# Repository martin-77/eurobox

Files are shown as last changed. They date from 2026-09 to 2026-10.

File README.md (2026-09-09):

# Eurobox CAD

Automated FreeCAD/OpenSCAD build and validation for the bicycle Eurobox mount.

Current target: **v50**.

## Current validated assembly preview

The single canonical repository preview is:

`cad/v50/assembly/PREVIEW_v50.png`

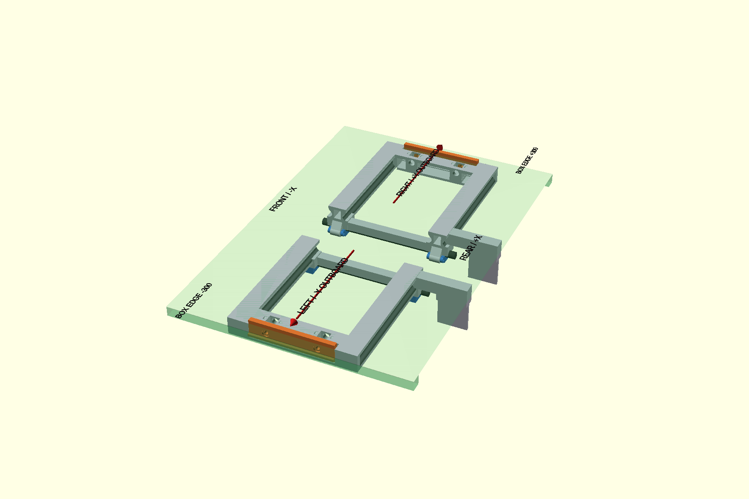
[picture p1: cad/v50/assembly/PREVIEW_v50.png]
Eurobox v50 validated assembly preview


The image is generated by the main GitHub Actions build from the same validated LEFT/RIGHT STL outputs that are published to `cad/v50/STL/`. `preview-stl/v50/` contains only the STL mirror and links back to this canonical preview; it does not keep a second PNG copy.

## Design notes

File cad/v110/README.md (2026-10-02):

# Eurobox carrier v110

V110 is a service-workaround release based on V100.

The existing V100 design is promoted unchanged, and one additional part is added:

- eurobox_v110_rack_nut_retainer_left_hand

This additional retainer is the exact X-mirror of the normal V100/V110 rack-nut retainer. Mirroring reverses the thread chirality while keeping the Z thread axis and insertion direction unchanged.

Use:
- current RIGHT base -> standard eurobox_v110_rack_nut_retainer
- current LEFT mirrored base -> eurobox_v110_rack_nut_retainer_left_hand

The left-hand service retainer tightens in the opposite rotational direction to the standard retainer.

This avoids reprinting the already-finished mirrored LEFT base. It is a compatibility workaround for the currently released mirrored female thread, not a reason to use opposite-handed threads in future base revisions.

All STL files are canonical binary STL. ASCII STL is rejected by the build/publish gate.

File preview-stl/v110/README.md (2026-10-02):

# v110 preview/print meshes

Complete binary STL mirror of cad/v110/STL/.

V110 adds a left-hand rack-nut service retainer for the currently mirrored LEFT base while retaining the standard retainer for the RIGHT base.

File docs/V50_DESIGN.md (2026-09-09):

# Eurobox v50 – finaler Konstruktionsstand

## Ziel

Werkzeuglos abnehmbarer PETG-Trägeradapter für eine quer montierte **600×400-mm-Eurobox** auf dem originalen Massload-3-leg-Gepäckträger des FOCUS THRON² EQP MY2023.

Verbindlich sind die gemessenen Datums aus `MEASUREMENTS.md`, die Parameter in `V50_DIMENSIONS.json` und die automatischen Validierungen. Alte v45/v47/v49-BREP-Geometrie ist keine Quelle für v50.

## Koordinatensystem

- X = Fahrtrichtung, **-X vorne / +X hinten**
- Y = je Seitenmodul vom Rackrohr nach außen zur Box
- Z = oben
- Rackrohrmitte je Modul = Y0/Z0

Global liegen die Rackrohrzentren bei Y=±55.335 mm und die äußeren Boxkanten exakt bei Y=±300.000 mm.

## Handed Bases und hinterer Montageanschlag

Die finale Konstruktion benötigt zwei unterschiedliche Bases:

- RIGHT: hinterer Anschlag lokal X=+150…+190 mm
- LEFT: gespiegelter Anschlag lokal X=-190…-150 mm

Das linke Modul wird bei der Montage 180° um Z gedreht. Dadurch landen beide Anschläge global am gleichen hinteren (+X) Ende. Vorne gibt es keinen Anschlag.

Der Anschlag ist 50 mm hoch, 4 mm dick und über einen tiefen Root/Gusset in den hinteren Lastpfad eingebunden. Er ist ausschließlich Montage-/Anti-Flop-Hilfe und kein zusätzlicher primärer Lastpfad. Ein separater V-Sattel an der diagonalen Rackstrebe wird nicht mehr exportiert.

## Rackbefestigung

Pro Seitenmodul zwei Klemmstationen bei X=±90 mm auf dem realen Ø12.42-mm-Rackrohr.

- obere starre Sattelhälfte in der Base
- separate flexible `rack_lower`-Hälfte
- Pivot Y=-12.0 / Z=-5.5 mm
- Pin Ø4.0 / Loch Ø4.6 mm
- Öffnungssweep 0…-75°
- Rohr muss spätestens bei -45° vollständig frei sein
- positiver Verschluss über M4-Schraube + separate Captive-Nut + Handknob
- gedruckte M4-Hardware für den Prototyp; Metall-M4 bleibt Drop-in-Option

## Tragstruktur und Druckorientierung

Die langen Lastpfade sind keine offenen I-Träger mehr. Final werden **geschlossene, verjüngte Solids** verwendet:

- 32 mm Breite oben
- 20 mm Breite unten
- 30 mm Bauhöhe
- 7 mm Taper
- Auflageoberseite Z=39.54 mm

Die komplette Base wird für den Druck 180° um X gedreht, sodass die Z=39.54-mm-Ebene auf dem Druckbett liegt. Crosshead, Guide und Cage sind auf diese Orientierung abgestimmt. Große strukturelle Supports und ein fester Unter-Rim-Bridge sind nicht vorgesehen.

## Boxklemmung – inboard statt außen

Die frühere außenliegende Schraub-/Nut-Käfiggeometrie überschritt die 600-mm-Boxbreite und ist verworfen.

Final sitzt die Boxklemmung **innen an der inneren Vertikalfläche des unteren 16.45-mm-Randes**:

- innere Randfläche lokal Y=228.215 mm
- Plattenkörper geschlossen Y=220.215…228.215 mm
- 4.2-mm-Untergriff unter der inneren Randkante
- 5.5 mm Öffnungsweg nach innen (-Y)
- 0.5 mm Klemm-Preload nach außen (+Y)
- zwei echte Durchgangsbohrungen in der Platte
- Schraubachsen X=±42 mm / Z=31 mm

Die Platte dreht nicht. Eine Spindelschulter überträgt die Klemmkraft; die axiale Retention zieht die Platte beim Öffnen aktiv zurück.

## Lead-Screw-System

Der Prototyp bleibt beim bewährten groben Druckgewinde:

- RH 8×2
- Gewindelänge 23 mm
- separate Lead-Nut-Cartridge
- Cross-Pin + C-Clip im unteren post-thread Tail
- Base selbst besitzt kein Arbeitsgewinde
- separater Knob und separate Retainer-Nut

Für die inboard-Anordnung werden Spindel, Lead-Nut, Knob und Retainer-Nut als **proper 180° Z rotation** orientiert. Es gibt keine Spiegelung der Thread-Solids; die RH-Chiralität bleibt erhalten. Positive Öffnung bewegt die Spindel nach -Y und verwendet entsprechend das umgekehrte Welt-Y-Rotationsvorzeichen.

## Harte Breitenregel

**Kein Bauteil der montierten Halterung darf die 600-mm-Eurobox seitlich überragen.**

CI ermittelt die tatsächlichen BoundBoxes von Base, Platte, Spindel, Lead-Nut, Knob, Retainer, Pin und Clip in:

- 0.5 mm Preload
- geschlossen
- 5.5 mm vollständig geöffnet

Aus Rack-CTC und dem jeweils größten lokalen Y-Maximum wird die globale Halterbreite berechnet. Obergrenze: 600.00 mm, numerische Toleranz 0.02 mm. Der Build schlägt bei Überschreitung fehl.

## Validierung vor Publish

Publish ist nur erlaubt, wenn gleichzeitig bestanden sind:

1. FreeCAD-Source-Solids gültig und einteilig;
2. STEP-Reimport gültig;
3. reales Ø12.42-mm-Rackrohr kollisionsfrei zur Base;
4. Rack-Lower-Sweep und Pivot-Hardware funktionsfähig;
5. hinterer Anschlag korrekt handed und nur hinten;
6. Box-Rim kollisionsfrei zur Base;
7. Platte geschlossen/offen kollisionsfrei und bei voller Öffnung freigegeben;
8. RH8×2 in korrekter Phase kollisionsfrei, falsche Phase mit echter Interferenz;
9. 0.5-mm-Preload mechanisch möglich;
10. vollständige Halterbreite ≤600 mm;
11. LEFT/RIGHT-STL unterschiedlich, physikalisch gespiegelt und watertight;
12. alle STL einteilig, winding-consistent und positiv volumig;
13. Assembly-Preview gerendert;
14. erst danach FCStd/STEP/STL in `cad/v50` publiziert.

## Druckziel

- Prusa CORE One L
- PETG
- 0.4-mm-Düse
- 0.20-mm-Layer
- mindestens 3 Perimeter für den strukturellen Prototyp
- kein großflächiger Support an den langen Lastpfaden oder Boxkontaktflächen

## Lastgrenze

Bis das konkrete Typenschild des montierten Massload-Trägers verifiziert ist, bleibt **16 kg Rack-Gesamtzuladung** die konservative Obergrenze. Vereinfachte 3×-Dynamikrechnungen sind ausschließlich Sanity-Checks und keine FEA oder Herstellerfreigabe.

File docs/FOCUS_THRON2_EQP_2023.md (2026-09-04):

# Focus THRON² EQP 2023 – Einbaukontext für Eurobox v50

## Zweck

Diese Datei trennt Hersteller-/Modellinformationen von direkt am Fahrrad gemessenen CAD-Daten. Werte aus Produktfotos werden **nicht** als Millimetermaße behandelt.

## Bestätigter Modellkontext

Zielrad ist ein **FOCUS THRON² EQP Modelljahr 2023**. Die FOCUS-Archivseite führt für MY23 eigene EQP-Datenblätter und eine eigene `THRON² EQP MY23`-Explosionszeichnung. Das Rad ist ein 29-Zoll-Fully mit F.O.L.D.-Hinterbau; der EQP-Gepäckträger ist ein **Massload 3-leg** und bewegt sich mit dem Hinterbau.

Für die CAD-Passung haben die Messwerte am konkreten Fahrrad Vorrang.

## Hersteller-/Quellenlage zum Gepäckträger

Die publizierte Lastangabe ist nicht völlig konsistent:

- mehrere MY23 Händler-/Spezifikationsseiten nennen den Massload 3-leg mit **25 kg max. load**;
- die aktuelle FOCUS-Archiv-FAQ für diese THRON²-EQP-Generation nennt für den eigenen Gepäckträger **16 kg**, bzw. 8 kg pro Seite.

v50 setzt deshalb **16 kg als konservative Systemobergrenze für den Originalträger**, bis Typenschild/Artikelnummer des tatsächlich montierten Gepäckträgers am Fahrrad geprüft sind. Der Adapter darf diese Herstellergrenze nicht erhöhen.

## Quellen

FOCUS Archiv THRON² EQP 2022–2024:
https://www.focus-bikes.com/int/archive/e-bikes/thron/pdp-thron-eqp-2022-2024-bosch

FOCUS Archiv / FAQ THRON² 2022–2024:
https://www.focus-bikes.com/de_de/archive/e-bikes/thron/pdp-thron-2022-2024-bosch

MY23 Händler-Spezifikation mit Massload 3-leg / 25 kg als Gegenquelle:
https://www.bikes.de/shop/e-bikes/marke.focus/focus-thron2-6-8-eqp-2023/

## Vom konkreten Fahrrad gemessene Geometrie

- oberes Gepäckträgerrohr: **Ø12.42 mm**
- Gepäckträger Außenbreite: **123.09 mm**
- Rohr Mitte–Mitte: **110.67 mm**
- nutzbare gerade Rohrlänge: ca. **220–240 mm**
- zwei Klemmpunkte pro Seitenmodul: **180 mm** Abstand
- Klemmpunkte: **X = ±90 mm**
- Rohrmitte → Euroboxkante: **244.665 mm**
- Boxauflage **Z = 39.54 mm**
- Schutzblechoberkante **Z = 34.54 mm**
- verbleibende vertikale Reserve: **5.00 mm**

## Relevanz der Focus-Geometrie

Die obere Gepäckträgerstruktur besitzt zwei lange parallele Längsrohre. Die MY23-3-leg-Konstruktion besitzt zusätzlich diagonale Streben Richtung Hinterradachse. Daraus folgen für v50 zwei getrennte Aufgaben:

1. **Hauptlast:** ausschließlich über die beiden weit auseinanderliegenden Rohrklemmen eines Seitenmoduls und die steifen Tragarme.
2. **Montage-Stabilisierung / Anti-Flop:** optionaler kleiner Anschlag an einer diagonalen Rack-Strebe, damit das Seitenmodul ohne Box nicht um das runde obere Rohr nach unten klappt.

Die Diagonalstrebe wird ausdrücklich **nicht** zum primären Lastpfad. Ihr Durchmesser und Winkel sind noch nicht gemessen; deshalb ist dort keine erfundene formschlüssige Klemme zulässig. Die erste v50-Ausführung verwendet einen universellen V-Sattel / Anschlag mit großzügiger Anpassbarkeit. Nach Vermessung kann daraus ein definierter Clip werden.

Damit bleibt die Konstruktion mit dem vollgefederten Hinterbau kompatibel: Es wird nichts zwischen Hauptrahmen und bewegtem Hinterbau verspannt.

## Herstellerlast

Bis zur Prüfung des konkreten Rack-Aufklebers gilt für die Konstruktion:

- konservative Nutzlastgrenze Originalträger: **16 kg**;
- 25 kg wird als dokumentierte MY23-Gegenangabe geführt, aber nicht als v50-Auslegungsfreigabe verwendet;
- ein 3×-Dynamikfall in der Balkenrechnung ist nur ein Geometrie-Sanity-Check und keine Freigabe oberhalb der Herstellerlast.

## Noch zu messen

- Durchmesser einer diagonalen 3-leg-Strebe;
- Winkel/Position dieser Strebe relativ zum oberen Rackrohr;
- exakte Querkontur des Schutzblechs;
- Typenschild/Artikelnummer und Lastangabe des tatsächlich montierten Massload-Trägers.

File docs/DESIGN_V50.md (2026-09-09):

# Eurobox v50 – Design-Dokumentation

Die frühere zweite, teilweise widersprüchliche v50-Konstruktionsbeschreibung wurde entfernt, damit Maße und Architektur nicht erneut auseinanderlaufen.

Verbindliche Quellen sind jetzt:

1. **`V50_DESIGN.md`** – finale Architektur und Konstruktionslogik.
2. **`V50_DIMENSIONS.json`** – maschinenlesbare harte Datums und finale Designparameter.
3. **`MEASUREMENTS.md`** – gemessene Werte und deren Herkunft.
4. **`VALIDATION_V50.md`** – Pflichtprüfungen vor einem Publish.
5. **`scripts/build_v50.py` + geordnete `apply_v50_*`-Finalisierung** – tatsächlich gebaute Geometrie.

Wichtig für den finalen v50-Stand: explizite handed LEFT/RIGHT-Bases mit genau einem hinteren Montageanschlag, geschlossene supportarme Lastpfade und eine **inboard** liegende Boxklemmung. Die komplette montierte Halterung muss innerhalb der globalen Euroboxkanten Y=±300 mm bleiben; CI behandelt 600 mm als Hard-Gate.

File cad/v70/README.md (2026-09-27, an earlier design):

# Eurobox V70 – integrated lead screw

V70 replaces the former separate knob / short retainer thread / plate clip stack
with one integrated lead screw plus one conical RH8x2 retainer nut.

## Changed parts

- `eurobox_v70_lead_screw_integrated`
  - integrated scalloped Ø30 x 7 mm grip
  - Ø13 x 2 mm outer thrust flange
  - Ø8.0 smooth journal
  - Ø8.4 x 0.8 mm pass-through hard-stop collar
  - unchanged RH8x2 working thread: core Ø6.5, major Ø8.0, pitch 2.0, length 24.0 mm

- `eurobox_v70_conical_retainer_nut`
  - same RH8x2 female geometry as the proven lead nut
  - Ø10.0 conical tip
  - Ø11.0 maximum outer diameter
  - two flats, 10.6 mm across flats
  - 5.4 mm total height

- `eurobox_v70_clamp_plate`
  - final V60 plate outline and hook retained
  - spindle bores changed to Ø8.8
  - former C-clip counterbores and service slots removed

## Fit budget

- Ø8.4 stop collar through Ø8.8 plate bore: 0.20 mm radial clearance
- Ø8.0 journal in Ø8.8 plate bore: 0.40 mm radial clearance
- retainer Ø10.0 tip over Ø8.8 bore: 0.60 mm radial capture
- retainer max Ø11.0 inside frozen BASE Ø11.8 spindle corridor: 0.40 mm radial clearance
- clamp axial play between flange and seated retainer: 0.15 mm
- inner clamp face to lead-nut front face: 7.8 mm
- retainer height: 5.4 mm
- nominal remaining gap before lead nut: 2.4 mm
- working-thread end from the outer clamp face: 32.15 mm
- former V60 working-thread end from the outer clamp face: 32.0 mm

## Frozen / reused V60 parts

The final V60 `base_left`, `base_right`, `rack_lower` and `lead_nut`
stay unchanged. The long RH8x2 working thread is deliberately kept on the
proven dimensions.

The old separate `knob`, `knob_retainer_nut` and `plate_retainer_clip`
are not used by the V70 box-clamp mechanism.

## Clamp v2 prototype

`eurobox_v70_clamp_v2` is the first full-width stepped clamp proposal based
on the measured underside geometry of the box:

- width: 187.30 mm
- total height: 88.57 mm
- screw axis: 15.00 mm above clamp bottom
- box underside: 30.00 mm above clamp bottom
- top of box protrusion: 63.57 mm above clamp bottom
- upper wall press height: 25.00 mm
- press-plane offset between protrusion and upper box wall: 18.50 mm
- V70 screw bores remain Ø8.80 mm at X=15.00 / 172.30 mm

The v2 STL is deliberately a robust fit prototype: the upper stepped block is
solid. Once the real box contact on both press planes is confirmed, the upper
section can be lightened without changing the contact geometry.

## Clamp / lead screw v3 prototype

V3 is an experimental redesign of the complete box-clamp spindle assembly. It
does not replace the frozen V60 base or lead nut.

### Clamp v3

- width: 187.30 mm
- total height: 88.57 mm
- screw axis remains 15.00 mm above clamp bottom
- box underside is 30.00 mm above clamp bottom
- nominal protrusion starts at 46.45 mm and ends at 63.57 mm
- protrusion pocket is 46.20..63.82 mm, giving 0.50 mm total vertical clearance
- lower contact is the primary clamp zone and projects to Z=27.00 mm
- upper 25 mm zone is secondary/stabilising and projects to Z=26.50 mm
- primary lower contact therefore reaches 0.50 mm farther toward the box
- the protrusion itself is recessed to the 8.00 mm backbone plane
- screw zone is reinforced to 10.00 mm thickness
- two 20 mm rear ribs connect the upper section to the screw stations
- spindle bores are Ø10.40 for rotating bushings

### Rotating bushing

One bushing is required for each spindle:

- body Ø10.00
- bore Ø8.35 for the Ø8.00 screw journal
- body length 10.25 mm
- clamp bearing thickness 10.00 mm
- resulting nominal axial freedom: 0.25 mm
- outer flange Ø14.00 x 2.00 mm

The screw shoulder and removable knob clamp the rotating bushing, not the
stationary clamp. This removes the previous conical retainer from the v3
prototype.

### Lead screw v3

From knob side toward the frozen lead nut:

- RH8x2 knob thread: 8.50 mm
- smooth Ø8.00 journal: 10.25 mm
- Ø10.80 x 2.00 mm shoulder
- RH8x2 working thread: 74.00 mm

The Ø10.80 shoulder remains inside the frozen Ø11.80 base spindle corridor
with 0.50 mm radial clearance. The working thread is the previous 24 mm plus
50 mm reserve so the spindle can remain engaged in the lead nut when the box
is removed.

### Knob v3

- separate scalloped Ø30 x 8 mm knob
- through female RH8x2 thread
- tightens against the rotating bushing flange

The screw-on knob is deliberately still a prototype. Its resistance to
self-loosening during repeated opening/closing must be checked physically
before this mechanism is treated as final.

### Binary STL build

Generate slicer-ready binary STLs explicitly; do not rely on GitHub text-file
serialization for STL output:

```sh
openscad --export-format binstl -o part.stl part.scad
```

All four locally rendered v3 meshes were checked as watertight, single-component
meshes before physical fit testing.

### GitHub binary STL validation

The v3 STLs committed in `cad/v70/STL/` are the exact locally validated
binary STL bytes. They were uploaded through the Git data API as base64 blobs
and then fetched again from the committed HEAD. Blob SHA and decoded byte
length matched the local files for all four parts:

- clamp v3: 42,684 bytes, blob `bc0a0dca49e2f693a67b32e8e2679b6cde894270`
- bushing v3: 76,884 bytes, blob `e368758d39aa2bbb31d311a99fd203082cdcaa78`
- lead screw v3: 717,384 bytes, blob `5c673d0054a5cbcd1952ab5690385c58cdc542ec`
- knob v3: 182,884 bytes, blob `49d15064ebe642e44e67df830a803bc18cfbb9c3`

This avoids the previous UTF-8 / ASCII STL serialization path.

## Clamp / spindle v4 prototype

V4 refines the v3 rotating-bushing concept.

### Recessed two-piece bushing

Each spindle uses two identical flanged bushing halves; therefore print four
halves per clamp.

- clamp screw-zone thickness: 12.00 mm
- central bushing bore: Ø10.40 mm
- flange pockets on both sides: Ø18.40 x 1.20 mm
- bushing body: Ø10.00 / bore Ø8.35
- flange: Ø18.00 x 2.20 mm
- each body length from pocket floor toward centre: 4.925 mm
- distance between clamp pocket floors: 9.60 mm
- two bodies together: 9.85 mm

The bushing stack is therefore 0.25 mm longer than the space between the pocket
floors. When the knob is tightened against the screw shoulder, the two rotating
bushing halves contact each other before either flange can clamp the stationary
clamp. The clamp keeps nominal axial freedom while the spindle assembly can be
tightened firmly.

### Clamp contact profile

The v3 box-contact strategy is retained:

- lower contact remains the primary clamp zone
- lower contact projects to Z=27.00 mm
- upper secondary contact projects to Z=26.50 mm
- primary contact therefore reaches 0.50 mm farther toward the box
- protrusion pocket remains Y=46.20..63.82 mm
- upper stabilising contact remains 25 mm high
- rear screw-zone ribs are widened to 22 mm

### Lead screw / knob

- screw-on knob thread: RH8x2, 8.50 mm
- smooth journal: Ø8.00 x 13.85 mm
- fixed screw shoulder: Ø11.20 x 2.20 mm
- frozen base spindle corridor: Ø11.80 mm
- shoulder clearance in corridor: 0.30 mm radial
- working RH8x2 thread: 74.00 mm
- knob has a Ø16.00 x 0.80 mm clamp-facing nose
- knob nose enters the Ø18.40 flange pocket and bears on the rotating bushing
  flange rather than on the stationary clamp

### STL validation

V4 STLs are committed as binary Git blobs. Before upload every local mesh was
checked as watertight and single-component. After the GitHub commit, each file
was fetched through the GitHub API and its Git blob SHA and decoded byte count
were compared against the local binary file.

Validated binary commit:

`b2da5c725c322b5b8c9f16271a7121fc01d0a1f4`

- clamp: 157884 bytes, blob `9bb2da5bfcb00de060973f195d5fac982948d2c6`
- bushing half: 76884 bytes, blob `acaf98f84e0cd1d092d5a1c521f13684dae50b1a`
- lead screw: 717384 bytes, blob `7c7a42eb9c8cdd79afef9ba98545d64c4ee73e70`
- knob: 227684 bytes, blob `e36c2ef022403b15d6af545b301b2013d89910e9`

All four GitHub blob SHAs and byte counts match their local validated binaries.

## Clamp / spindle v5 prototype

V5 refines v4 in three areas:

- the visible outer face of the screw-on knob is closed; its RH8x2 female
  thread is blind
- the upper secondary box-contact zone is reduced to 16.20 mm, exactly the
  same actual height as the lower primary-contact zone; total clamp height is
  reduced from 88.57 mm to 80.02 mm
- the bearing-centering interfaces are conical

Clamp-to-bushing:
- clamp seat Ø18.40 -> Ø10.40 over 1.60 mm
- bushing seat Ø18.00 -> Ø10.00 over 1.60 mm
- cylindrical body Ø10.00 in Ø10.40 bore
- two bushing bodies retain 0.25 mm total axial overlength, so the rotating
  bushing stack is clamped rather than the stationary clamp

Bushing-to-screw / bushing-to-knob:
- each bushing outer face has a shallow female centering cone
- screw shoulder and knob use matching male centering cones
- screw and knob do not bear directly on the clamp

Contact profile:
- lower primary contact Y=30.00..46.20 mm, height 16.20 mm
- protrusion pocket Y=46.20..63.82 mm
- upper secondary contact Y=63.82..80.02 mm, height 16.20 mm
- lower primary contact still projects 0.50 mm farther toward the box

Lead screw:
- removable-knob RH8x2 section 8.50 mm
- smooth Ø8.00 journal 13.95 mm
- conical centering shoulder, max Ø11.20 mm
- main RH8x2 working thread remains 74.00 mm

The v5 STLs are generated locally as binary STL and validated as watertight,
single-component meshes before upload. GitHub files are written as base64 Git
blobs and checked against the exact local payload.

## Clamp v6 — support-free backing

V6 changes only the clamp body. The V5 bushing halves, lead screw and knob are
unchanged and remain compatible.

V5 had the reinforced screw region extending to Z=-4 while the majority of
the rear clamp face started at Z=0. In the intended broad-face print
orientation this left a 4 mm unsupported region.

V6 extends the complete clamp backbone from Z=-4 to Z=+8, producing a single
continuous planar bed face. The added region is deliberately a closed CAD
volume rather than explicit honeycomb. Material saving and internal structure
are handled by the slicer.

Recommended baseline for this part:

- PETG
- 0.20 mm layers
- 30% gyroid
- 7 bottom layers
- 7 top layers
- 3 perimeters or the stronger project profile

At 0.20 mm, seven bottom and seven top layers provide 1.4 mm skins on both
sides of the 12 mm backbone; the remaining core is filled with gyroid. This
keeps the complete underside printable without support while retaining a
continuous load path.

The V5 box-contact dimensions and both conical bushing seats remain unchanged.

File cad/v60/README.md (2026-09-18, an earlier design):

# Eurobox carrier v60

Canonical clean rebuild generated and hard-validated by `scripts/build_v60.py`, `scripts/build_v60_continuous_carrier.py` and `scripts/build_v60_full.py`.

Structural principle: one continuous rack-side carrier. The two rack clamps and the rear stop hang from this carrier; the long box-support holms fuse into the same load path.

- `FCStd/` — individual editable FreeCAD parts
- `STEP/` — neutral CAD exports
- `STL/` — printable handed meshes and removable clamp hardware (the rack hand knob is component-owned and published by its fast workflow)
- `assembly/` — installed-orientation PNG
- `validation/` — machine-readable hard-check and timing reports
- workflow artifact `eurobox-v60-complete` — complete generated FreeCAD assembly and all proof outputs

The box clamp uses the v50 direct architecture: the BASE is a smooth housing and the only working RH8x2 female thread is a removable lead-nut cartridge retained by cross-pin and clip. There is no intermediate clamp cassette or later front rebuild. The rack closure uses one final matched 12x3 service-retainer pair. Its complete screw-major envelope must be open at the real BASE surface, and CI inserts the actual retainer from free space before accepting the build.

`validation/TIMING_v60.json` records measured stage/operation durations from the GitHub runner so expensive OCC operations can be optimized from data rather than guesswork.

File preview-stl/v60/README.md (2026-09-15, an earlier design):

# v60 preview/print meshes

Validated v60 STL exports mirrored from `cad/v60/STL/` by the production v60 workflow.

`eurobox_v60_preview.png` shows the actual installed orientation: RIGHT is translated to the +Y rack tube; LEFT is the handed printable STL rotated 180 degrees about Z and translated to the -Y rack tube. The long carriers therefore point outward on both sides.

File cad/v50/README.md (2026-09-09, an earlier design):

# Eurobox v50 CAD
Updated automatically only after source, assembly, mechanism and STL validation pass.

Canonical assembly preview: [PREVIEW_v50.png](assembly/PREVIEW_v50.png)

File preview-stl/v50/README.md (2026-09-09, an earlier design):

# Eurobox v50 STL mirror
This directory mirrors the validated STL files only.

The single canonical assembly preview is:
`../../cad/v50/assembly/PREVIEW_v50.png`

[Open the current validated assembly preview](../../cad/v50/assembly/PREVIEW_v50.png)

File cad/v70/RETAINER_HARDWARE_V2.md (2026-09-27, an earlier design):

# V70 retaining hardware v2 — physical-fit candidates

These parts stay in V70 until they have been physically accepted. Do not copy
them into V80 yet.

## Corrected lead-nut retaining pin

The rejected short pin used the lead-nut lug width instead of the complete
frozen BASE service geometry.

Frozen BASE interface:
- head pocket: X = -14.35 .. -11.65 mm
- clip pocket: X = +11.20 .. +13.20 mm
- service path: X = -14.35 .. +15.05 mm

Corrected candidate:
- head: Ø6.50 x 2.00 mm, X = -13.65 .. -11.65
- shaft: Ø3.00 mm, X = -11.65 .. +11.40
- retaining groove: Ø2.40 x 1.60 mm, X = +11.40 .. +13.00
- end tip: Ø3.00 x 1.50 mm, X = +13.00 .. +14.50
- total length: **28.15 mm**

The groove is centred in the existing 2.00 mm clip pocket, leaving 0.20 mm
pocket clearance at each axial side. The tip ends 0.55 mm before the frozen
service-path end.

## Tight clip rule

The clip is installed sideways directly into the reduced groove. It never has
to open over the larger shaft.

For the two clips still used by the current carrier:
- relaxed ID = groove diameter - 0.20 mm
- throat = relaxed ID - 0.10 mm
- flared entry = groove diameter + 0.20 mm
- thickness = 1.30 mm
- compact original C-clip form retained

Lead-nut pin clip:
- groove Ø2.40
- relaxed ID Ø2.20
- throat 2.10
- entry 2.60
- OD 6.40
- t 1.30
- groove width 1.60 => 0.15 mm axial clearance each side

Rack-pin clip:
- groove Ø3.10
- relaxed ID Ø2.90
- throat 2.80
- entry 3.30
- OD 6.40
- t 1.30

The old V60 plate-retainer clip is obsolete with the current two-piece bushing
+ lead-screw + knob clamp mechanism and is deliberately not rebuilt.

All three STL files in this test set are true binary STL Git blobs.

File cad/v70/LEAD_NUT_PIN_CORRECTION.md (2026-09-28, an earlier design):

# V70 lead-nut retaining pin correction

Status: **RECALCULATED / RELEASED TO V80**

The earlier retaining pin was physically too short and is rejected.

The replacement was re-derived from the actual frozen V60/V80 base service geometry, including both retaining walls, the complete service path and the external clip pocket.

## Frozen service geometry

- head pocket: X = -14.35 .. -11.65 mm, Ø6.70 mm
- retaining wall, left: X = -11.35 .. -8.20 mm
- retaining wall, right: X = +8.20 .. +11.35 mm
- clip pocket: X = +11.20 .. +13.20 mm, Ø7.10 mm
- complete shaft service path: X = -14.35 .. +15.05 mm, Ø3.40 mm

## Released retaining pin

- head: -13.65 .. -11.65 mm, Ø6.50 mm
- shaft: -11.65 .. +11.40 mm, Ø3.00 mm
- clip groove: +11.40 .. +13.00 mm, Ø2.40 mm
- tip: +13.00 .. +14.50 mm, Ø3.00 mm
- total length: 28.15 mm

This leaves 0.55 mm end clearance to the +15.05 mm service-path limit while the Ø3.00 shaft passes completely through both retaining walls.

## Matching clip

Released clip geometry is the V70 v4 / V80 clip:

- V50-style closed-ring topology
- relaxed ID Ø2.10 mm
- opening 1.60 mm
- OD Ø7.00 mm
- thickness 1.30 mm
- target pin groove Ø2.40 mm × 1.60 mm

The clip therefore has 0.30 mm total axial clearance in the groove and 0.10 mm diametral clearance to the Ø7.10 base clip pocket.

The prior short pin and the earlier incompatible clip experiments remain rejected.

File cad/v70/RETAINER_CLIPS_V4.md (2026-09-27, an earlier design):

# V70 retaining clips v4

Physical-fit candidates only. Do not promote to V80 until accepted.

Reference geometry:
`cad/v50/STL/eurobox_v50_plate_retainer_clip.stl`

V4 deliberately returns to the original V50 plate-retainer topology:
a nearly closed circular ring with one narrow rectangular side opening.
There is no flared/V-shaped lead-in.

## Lead-nut pin clip v4
- target groove: Ø2.40 mm
- relaxed clip ID: Ø2.10 mm
- diametral preload: 0.30 mm
- side opening: 1.60 mm
- outer diameter: Ø7.00 mm
- thickness: 1.30 mm

## Rack-pin clip v4
- target groove: Ø3.10 mm
- relaxed clip ID: Ø2.80 mm
- diametral preload: 0.30 mm
- side opening: 2.15 mm
- outer diameter: Ø7.50 mm
- thickness: 1.30 mm

The opening ratios are based on the proven V50 plate-retainer clip
(3.80 / 4.90 = 0.7755), rounded slightly tighter.

Both STLs are committed as true binary STL Git blobs, not ASCII STL.

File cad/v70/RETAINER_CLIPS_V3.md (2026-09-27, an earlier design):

# V70 retaining clips v3 — tighter physical-fit candidates

The corrected 28.15 mm lead-nut retaining pin v2 remains unchanged.

The v3 clips keep the compact original C-clip form and are installed sideways
directly onto the reduced groove. They do not need to pass over the larger
shaft diameter.

## Lead-nut retaining clip v3
- groove: Ø2.40 mm
- relaxed clip ID: Ø2.10 mm
- diametral preload: 0.30 mm
- throat: 2.00 mm
- flared entry: 2.60 mm
- OD: Ø6.40 mm
- thickness: 1.30 mm
- groove width: 1.60 mm => 0.15 mm nominal axial clearance per side

Validated binary STL:
- bytes: 9,484
- SHA-256: 1a36c2c459a72516ccf0bd104ff67a49ee63dc00997d1237245f047b2b422361
- Git blob: 744738a31610750770edf7287cbd943a864745d1

## Rack-pin clip v3
- groove: Ø3.10 mm
- relaxed clip ID: Ø2.80 mm
- diametral preload: 0.30 mm
- throat: 2.70 mm
- flared entry: 3.30 mm
- OD: Ø6.40 mm
- thickness: 1.30 mm

Validated binary STL:
- bytes: 14,284
- SHA-256: 890a553be9b6f44e6d019b033e873381272520047e6517cebb05d4f0934d5252
- Git blob: 5f0f075772a6b07583956448bffe4562f946149f

Both meshes were locally checked watertight and single-component.
They remain V70 test parts until physical approval and are not copied to V80.

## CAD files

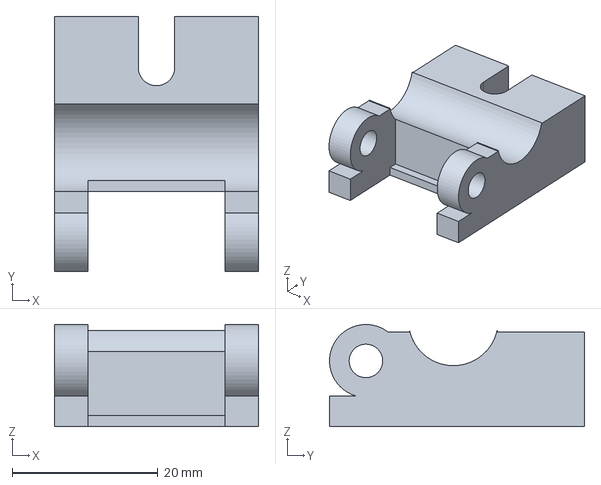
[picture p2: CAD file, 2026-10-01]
cad/v110/STEP/eurobox_v110_rack_lower.step
28.0 x 35.0 x 14.0 mm

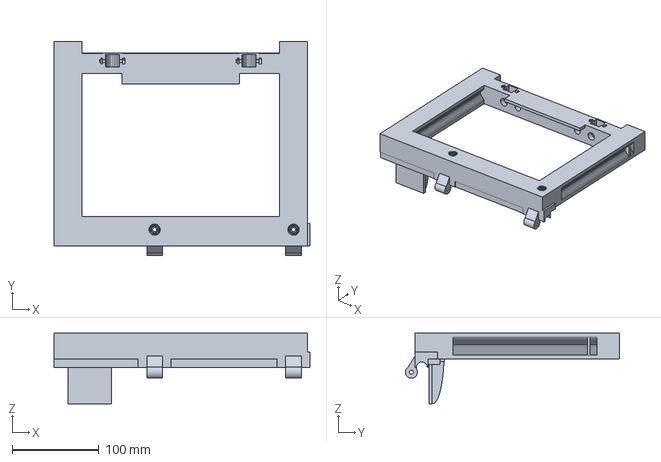
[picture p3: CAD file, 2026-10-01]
cad/v110/STEP/eurobox_v110_base_left.step
295.0 x 247.0 x 81.5 mm

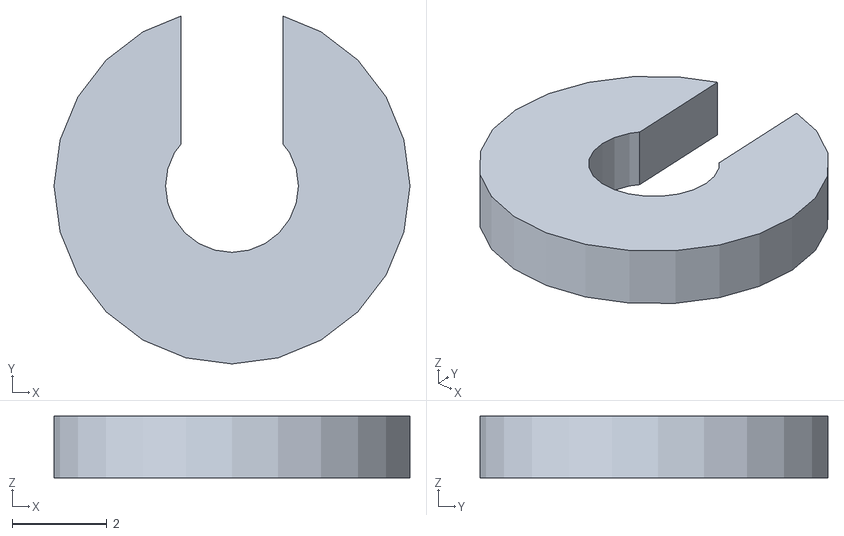
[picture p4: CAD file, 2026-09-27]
cad/v110/STL/eurobox_v110_rack_pin_clip.stl
7.50 x 7.33 x 1.30

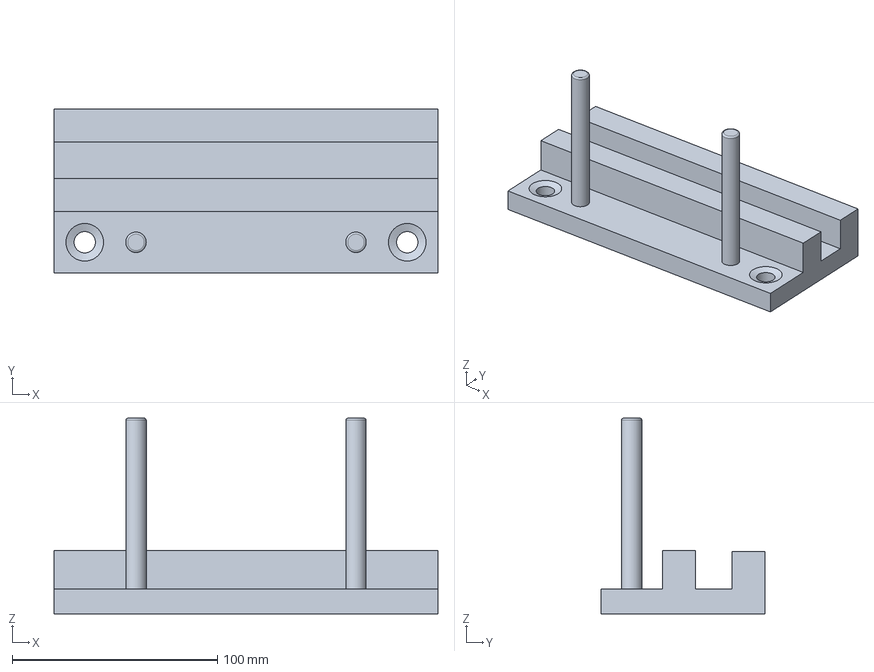
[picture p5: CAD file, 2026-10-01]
cad/v110/STEP/eurobox_v110_clamp.step
187.3 x 80.0 x 95.4 mm

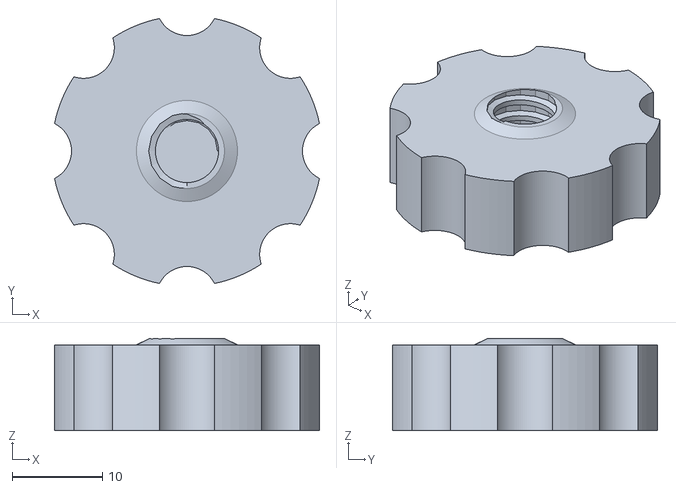
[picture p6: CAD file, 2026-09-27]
cad/v110/STL/eurobox_v110_knob.stl
29.4 x 29.4 x 10.2

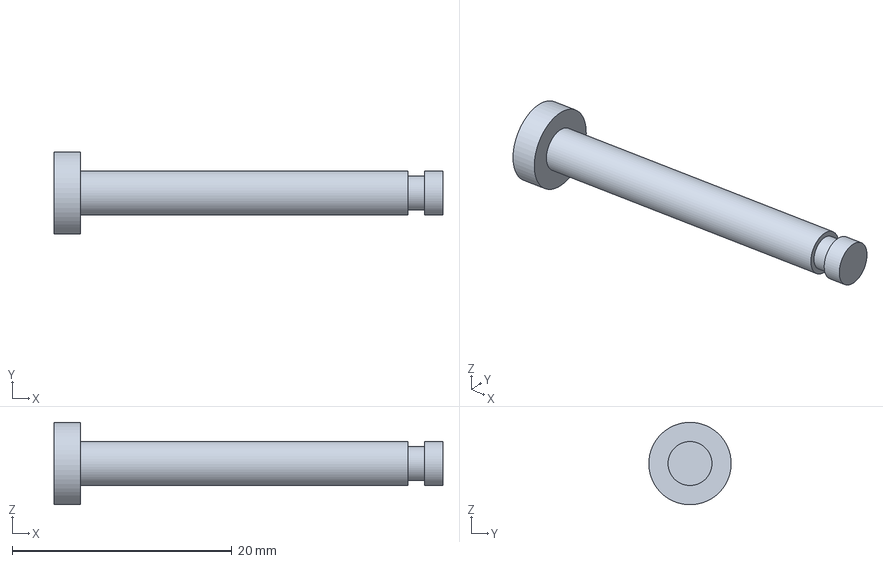
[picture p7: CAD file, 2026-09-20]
cad/v110/STEP/eurobox_v110_rack_pin.step
35.4 x 7.50 x 7.49 mm

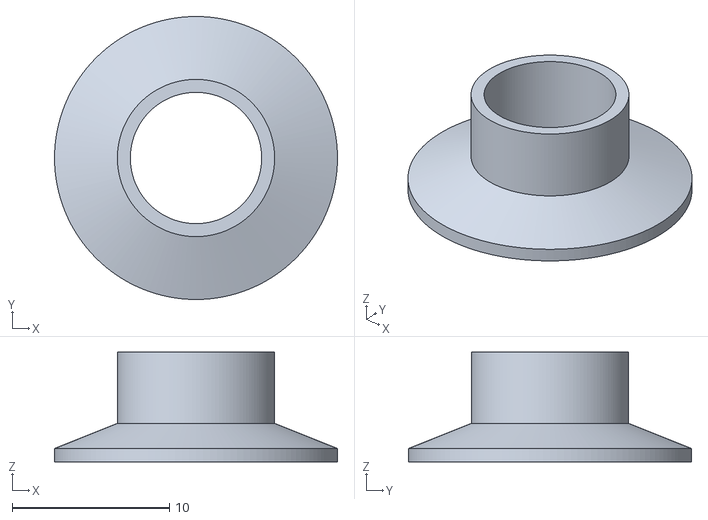
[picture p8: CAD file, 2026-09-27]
cad/v110/STL/eurobox_v110_bushing_half.stl
18.0 x 18.0 x 6.97

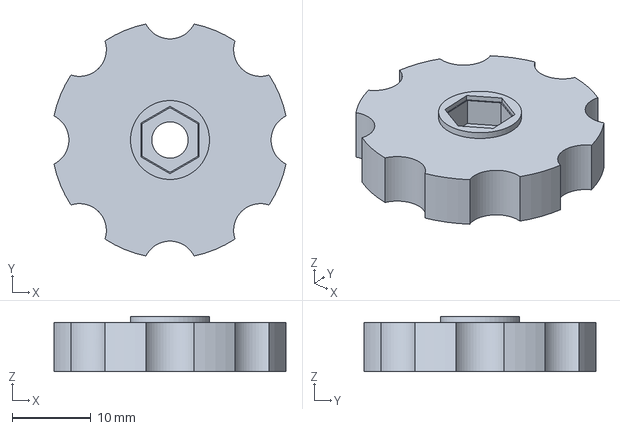
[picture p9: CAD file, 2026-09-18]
cad/v110/STEP/eurobox_v110_rack_hand_knob.step
29.4 x 29.4 x 7.00 mm

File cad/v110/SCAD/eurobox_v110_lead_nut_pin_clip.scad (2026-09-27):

$fn=24;

module clip(od,id,t,ow){
  difference(){
    difference(){
      cylinder(d=od,h=t);
      translate([0,0,-0.1]) cylinder(d=id,h=t+0.2);
    }
    translate([-ow/2,0,-0.2]) cube([ow,od/2+1,t+0.4]);
  }
}

// V70 v4 lead-nut retaining-pin clip.
// Reference topology: V50 plate-retainer clip.
// Target groove Ø2.40; relaxed ID Ø2.10; opening 1.60.
// Outer diameter widened to Ø7.00 for stronger arms.
clip(7.00,2.10,1.30,1.60);

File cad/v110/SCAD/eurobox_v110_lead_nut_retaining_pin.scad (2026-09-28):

$fn=48;

module cyl_x(d,l,x0) {
    translate([x0,0,0]) rotate([0,90,0]) cylinder(d=d,h=l);
}

// V80 lead-nut retaining pin.
// Recalculated from the actual frozen V60/V80 BASE service geometry:
// head pocket -14.35..-11.65, clip pocket +11.20..+13.20,
// service path -14.35..+15.05.
//
// Released geometry:
// head  -13.65..-11.65  Ø6.50
// shaft -11.65..+11.40  Ø3.00
// groove +11.40..+13.00 Ø2.40
// tip    +13.00..+14.50 Ø3.00
// total length = 28.15 mm
//
// Matching V80 clip:
// ID Ø2.10, opening 1.60, OD Ø7.00, thickness 1.30.

union() {
    cyl_x(6.50,2.00,-13.65);
    cyl_x(3.00,23.05,-11.65);
    cyl_x(2.40,1.60,11.40);
    cyl_x(3.00,1.50,13.00);
}

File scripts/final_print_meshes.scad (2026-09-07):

// v50 fallback/manual printable mesh generator
// CI no longer overwrites the canonical FreeCAD/OCC lead-screw STL with this
// file. Keep this source geometrically aligned for manual OpenSCAD use.
// Use:
//   openscad -D 'part="spindle"' -o <output.stl> final_print_meshes.scad
//   openscad -D 'part="rack_m4_nut"' -o <output.stl> final_print_meshes.scad

$fn=96;
part="spindle";

pitch=2.0;
core_r=3.25;
major_r=4.0;
root_w=0.72;
crest_w=0.30;

module rh_thread_z(length) {
  union() {
    cylinder(r=core_r,h=length,$fn=96);
    linear_extrude(height=length,
                   twist=360*length/pitch,
                   slices=ceil(length/pitch*28),
                   convexity=30)
      polygon(points=[
        [core_r-0.08,-root_w/2],
        [major_r,-crest_w/2],
        [major_r, crest_w/2],
        [core_r-0.08, root_w/2]
      ]);
  }
}

module hex_prism_z(af,h) {
  cylinder(r=af/sqrt(3),h=h,$fn=6);
}

module spindle_z() {
  union() {
    cylinder(r=3.0,h=0.42);
    translate([0,0,0.38]) cylinder(r=2.5,h=1.44);
    translate([0,0,1.78]) cylinder(r=3.0,h=6.24);
    translate([0,0,7.98]) cylinder(r=5.5,h=1.84);
    translate([0,0,9.78]) cylinder(r=core_r,h=23.04);
    translate([0,0,9.8])
      linear_extrude(height=23.0,
                     twist=360*23.0/pitch,
                     slices=ceil(23.0/pitch*28),
                     convexity=30)
        polygon(points=[
          [core_r-0.08,-root_w/2],
          [major_r,-crest_w/2],
          [major_r, crest_w/2],
          [core_r-0.08, root_w/2]
        ]);
    // Canonical v50 drive: 8x8 mm square, not a nut-like AF10 hex collar.
    translate([-4.0,-4.0,32.78]) cube([8.0,8.0,4.54]);
    translate([0,0,37.28]) cylinder(r=core_r,h=7.02);
    translate([0,0,37.30])
      linear_extrude(height=7.0,
                     twist=360*7.0/pitch,
                     slices=ceil(7.0/pitch*28),
                     convexity=30)
        polygon(points=[
          [core_r-0.08,-root_w/2],
          [major_r,-crest_w/2],
          [major_r, crest_w/2],
          [core_r-0.08, root_w/2]
        ]);
  }
}

// Rack M4 nut: true radial-Z helical groove, not a twisted XY ribbon.
rack_m4_pitch=0.7;
rack_m4_nut_af=7.0;
rack_m4_nut_h=5.6;
rack_m4_bore_r=1.66;          // Ø3.32 crest/open bore
rack_m4_groove_inner_r=1.58;  // 0.08 mm overlap into bore -> guaranteed open groove
rack_m4_groove_outer_r=2.20;  // Ø4.40 groove root
rack_m4_inner_half_z=0.14;    // ~0.28 mm groove width at bore
rack_m4_outer_half_z=0.08;
rack_m4_ext=0.7;
rack_m4_total_h=rack_m4_nut_h+2*rack_m4_ext;
rack_m4_turns=rack_m4_total_h/rack_m4_pitch;
rack_m4_steps=ceil(rack_m4_turns*48);
rack_m4_a0=-360;
rack_m4_a1=360*(rack_m4_turns-1);

function rack_ang(i)=rack_m4_a0+(rack_m4_a1-rack_m4_a0)*i/rack_m4_steps;
function rack_zc(i)=rack_m4_pitch*rack_ang(i)/360;
function rack_pt(r,a,z)=[r*cos(a),r*sin(a),z];

rack_thread_pts=[
  for(i=[0:rack_m4_steps])
    let(a=rack_ang(i),z=rack_zc(i))
      each [
        rack_pt(rack_m4_groove_inner_r,a,z-rack_m4_inner_half_z),
        rack_pt(rack_m4_groove_outer_r,a,z-rack_m4_outer_half_z),
        rack_pt(rack_m4_groove_outer_r,a,z+rack_m4_outer_half_z),
        rack_pt(rack_m4_groove_inner_r,a,z+rack_m4_inner_half_z)
      ]
];
rack_thread_sides=[
  for(i=[0:rack_m4_steps-1]) for(j=[0:3])
    [4*i+j,4*(i+1)+j,4*(i+1)+((j+1)%4),4*i+((j+1)%4)]
];
rack_thread_start=[[0,1,2,3]];
rack_thread_e=4*rack_m4_steps;
rack_thread_end=[[rack_thread_e+3,rack_thread_e+2,rack_thread_e+1,rack_thread_e]];

module rack_m4_true_helical_groove() {
  polyhedron(points=rack_thread_pts,
             faces=concat(rack_thread_sides,rack_thread_start,rack_thread_end),
             convexity=60);
}

module rack_m4_female_cutter() {
  union() {
    translate([0,0,-rack_m4_ext])
      cylinder(r=rack_m4_bore_r,h=rack_m4_total_h,$fn=96);
    rack_m4_true_helical_groove();
  }
}

module rack_m4_nut_z() {
  difference() {
    hex_prism_z(rack_m4_nut_af,rack_m4_nut_h);
    rack_m4_female_cutter();
  }
}

if (part == "spindle")
  rotate([-90,0,0]) render(convexity=40) spindle_z();
else if (part == "rack_m4_nut")
  render(convexity=80) rack_m4_nut_z();

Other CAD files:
preview-stl/v110/eurobox_v110_rack_lower.stl
preview-stl/v110/eurobox_v110_base_left.stl
cad/v110/STEP/eurobox_v110_base_right.step
preview-stl/v110/eurobox_v110_base_right.stl
preview-stl/v110/eurobox_v110_clamp.stl
preview-stl/v110/eurobox_v110_rack_hand_knob.stl
preview-stl/v110/eurobox_v110_rack_pin.stl
cad/v110/SCAD/eurobox_v110_rack_pin_clip.scad
cad/v110/FCStd/eurobox_v110_base_left.FCStd
cad/v110/FCStd/eurobox_v110_base_right.FCStd
cad/v110/FCStd/eurobox_v110_clamp.FCStd
cad/v110/FCStd/eurobox_v110_lead_nut.FCStd
cad/v110/FCStd/eurobox_v110_rack_hand_knob.FCStd
cad/v110/FCStd/eurobox_v110_rack_lower.FCStd
cad/v110/FCStd/eurobox_v110_rack_nut_retainer.FCStd
cad/v110/FCStd/eurobox_v110_rack_nut_retainer_left_hand.FCStd
cad/v110/FCStd/eurobox_v110_rack_pin.FCStd
cad/v110/SCAD/eurobox_v110_bushing_half.scad
cad/v110/SCAD/eurobox_v110_knob.scad
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

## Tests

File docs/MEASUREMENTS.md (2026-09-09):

# Eurobox v50 – Maße und feste Datums

Koordinatensystem: **X = Fahrtrichtung** (`-X` vorne, `+X` hinten), **Y = vom jeweiligen Gepäckträgerrohr nach außen**, **Z = oben**. Gemessene Werte werden nicht mit aus Fotos geschätzten Millimeterwerten vermischt.

## Direkt gemessen / daraus fest berechnet

| Parameter | Wert |
|---|---:|
| Eurobox quer | 600.00 mm |
| Eurobox in Fahrtrichtung | 400.00 mm |
| unterer Rand horizontal | 16.45 mm |
| unterer Rand vertikal | 16.45 mm |
| Gepäckträgerrohr Ø | **12.42 mm** |
| Gepäckträger Außenbreite | 123.09 mm |
| Rohr Mitte–Mitte | 110.67 mm |
| Rohrmittelpunkte global Y | ±55.335 mm |
| Klemmenabstand X | 180.00 mm |
| Klemmenpositionen je Modul | X = ±90.00 mm |
| Rohrmitte → äußere Boxkante | 244.665 mm |
| globale Boxkanten | Y = ±300.000 mm |
| Rohroberkante | Z = +6.21 mm |
| Schutzblechoberkante | Z = +34.54 mm |
| Boxauflage | Z = +39.54 mm |
| Restabstand Boxauflage → Schutzblech | 5.00 mm |

Ø12.00 mm aus frühen Varianten ist **kein** gültiger Rackdurchmesser. Die starre Base wird gegen das reale Ø12.42-mm-Rohr geprüft.

## Finale v50-Tragstruktur

Die frühere offene Doppelsteg-I-Geometrie ist nicht mehr der finale Druckstand. Die beiden langen Lastpfade pro Seitenmodul sind **geschlossene, nach unten verjüngte Solids**, damit PrusaSlicer den Innenbereich mit Infill statt mit großflächigem Support behandeln kann.

- oben 32 mm breit
- unten 20 mm breit
- 30 mm Bauhöhe
- 7 mm Verjüngung
- Oberseite / Auflage Z = 39.54 mm
- Base wird für den Druck um 180° um X gedreht; Z=39.54 liegt dann auf dem Bett

Crosshead, Guides und Käfig sind so ausgelegt, dass kein großes festes Bauteil unter dem hängenden Boxrand nach außen läuft.

## Rack-Klemme

Je Seitenmodul gibt es zwei identische Rack-Klemmstationen. Die obere Hälfte ist Bestandteil der Base, die untere Hälfte `rack_lower` ist separat.

- reales Rohr Ø12.42 mm
- obere starre Sattelkontur ca. Ø12.52 mm
- untere PETG-Sattelkontur ca. Ø12.30 mm
- Pivot Y = -12.0 mm / Z = -5.5 mm
- Pin Ø4.0 mm
- Pinbohrung Ø4.6 mm
- Öffnungssweep bis -75°; spätestens bei -45° muss das Rohr frei sein
- positiver Verschluss über separate M4-Schraube, separate Captive-Nut und Handknob

## Rear-only Montageanschlag

Die finale Base ist **handed**. Rechts sitzt der einzige Anschlag lokal hinten bei X=+150…+190 mm, links gespiegelt bei X=-190…-150 mm. Nach der 180°-Montagedrehung des linken Moduls liegen beide Anschläge global am gleichen hinteren Ende.

Der Anschlag ist 50 mm hoch und 4 mm dick und über Root/Gusset an den hinteren Lastpfad angebunden. Er ist Montage-/Anti-Flop-Hilfe, **kein zusätzlicher Hauptlastpfad**. Ein separater V-Sattel an der diagonalen Rackstrebe gehört nicht mehr zum finalen Teilesatz.

## Box-Klemmung – innerhalb des 600-mm-Umrisses

Die frühere außenliegende Spindel-/Nut-Käfiggeometrie war zu breit. Final sitzt der komplette Schraubmechanismus **innen am unteren Boxrand**.

- innere Randfläche lokal Y = 228.215 mm
- geschlossene Plattenkörper-Lage Y = 220.215…228.215 mm
- Untergriff 4.2 mm unter der inneren Randkante
- Öffnungsweg 5.5 mm **nach innen (-Y)**
- definierter Preload 0.5 mm nach außen (+Y)
- Spindelachsen X = ±42 mm
- Spindelachse Z = 31.0 mm
- RH 8×2, Gewindelänge 23 mm
- separate gedruckte Lead-Nut mit Cross-Pin/C-Clip

Die vollständige Halterung muss in Preload-, geschlossener und vollständig geöffneter Stellung zwischen global Y=-300 und +300 bleiben. Das ist ein **Hard-Gate in CI**, nicht nur ein Reportwert.

## Belastungsgrenze

Für den konkreten v50-Entwurf wird konservativ mit **16 kg maximaler Rack-Gesamtzuladung** gearbeitet, solange das Typenschild des tatsächlich montierten Massload-Trägers nicht einen anderen belastbaren Wert bestätigt. Der 3×-Dynamikfall in den Skripten ist nur ein Sanity-Check, kein FEA-Nachweis und keine Freigabe oberhalb der Herstellerlast.

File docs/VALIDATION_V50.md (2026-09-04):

# v50 – automatische Validierung

Ein Build darf nur als `eurobox-v50` Artefakt veröffentlicht werden, wenn alle harten Checks bestanden sind.

## Geometrie

Für jedes STEP-Teil nach Export und erneutem STEP-Import:

- `Shape.isValid() == True`
- genau 1 Solid pro druckbarem Einzelteil
- positive Volumina
- plausible Bounding Box

Für jedes STL:

- watertight
- winding consistent
- genau 1 zusammenhängende Komponente
- positives Volumen

## Reales Gepäckträgerrohr

Prüfkörper: Zylinder Ø12.42 mm, Achse X.

- starre Base gegen Rohr: kein unerwünschtes Kollisionsvolumen
- obere Sattelkontur muss den dokumentierten Freiraum einhalten
- untere PETG-Klemmhälfte: nur die dokumentierte kleine Vorspannung ist erlaubt

## Rohrklemme / Pins

- beide Klemmenpositionen X = ±90 mm
- alle Pinbohrungen zylindrisch und gleichachsig
- Pin Ø4.0 mm
- Bohrung Ø4.6 mm
- geschlossene Base ↔ Rack-Lower ohne unerwünschte Solid-Kollision
- Pins laufen ausschließlich durch die vorgesehenen Lochvolumina
- Pin-Clip muss in der vorgesehenen Nut sitzen können

## Integrierter Anti-Rotationsanschlag

Der separate V-Sattel/Diagonalstreben-Stabilisator ist verboten und darf in v50 nicht mehr erzeugt werden.

Stattdessen werden an beiden Klemmenstationen integrierte nach unten gezogene Innenanschläge geprüft:

- Anschlag ist Bestandteil der Base und mit der Klemmenwurzel massiv verbunden
- X-Breite Ziel 24 mm je Station
- Wandstärke Ziel 6 mm
- Wurzelradius Ziel ≥4 mm
- Kontaktbereich umfasst den Bereich um Z=0 des oberen Gepäckträgerrohres
- nominaler Freiraum zur definierten Rack-Edge-/Tangential-Prüffläche 0.15–0.25 mm
- keine Kollision mit dem Ø12.42-mm-Prüfrohr in Montageposition
- keine Kollision mit Rack-Lower in geschlossenem Zustand
- Rack-Lower muss den vorgesehenen Montage-/Öffnungsweg weiterhin erreichen
- kein Teil des Anschlags darf in den konservativen Schutzblech-Freiraum außerhalb der lokalen Klemmenzone hineinragen

Zusätzlich wird eine kleine Rotationsprüfung ausgeführt: Bei simuliertem Abkippen des Außenarms muss der Innenanschlag vor einer relevanten Rotation die Rack-Edge-Prüffläche berühren. Damit wird bestätigt, dass er tatsächlich als Anti-Rotationsanschlag wirkt und nicht nur dekorativ in der Nähe liegt.

## Boxrand

Konservatives Prüfvolumen:

- 16.45 mm horizontal
- 16.45 mm vertikal
- Außenkante Y = 244.665 mm
- Auflage Z = 39.54 mm

Checks:

- geschlossene Platte: kein unerwünschtes Volumen im Boxrand
- Untergriff liegt hinter/unter der Außenkante
- geöffnet bei +4.5 mm: Untergriff gibt Außenkante frei
- Base/Platte: bei 0, 1, 2, 3, 4 und 4.5 mm Öffnung kein Kollisionsvolumen

## Plattenführung

- keine offenen T-Schlitze im tragenden Hauptkörper
- Schraubenbohrungen sind echte Durchgangsbohrungen
- Platte kann nur entlang Y verfahren
- Führungsspiel 0.35–0.45 mm je Seite

## Lead Screw

Print-Prototyp:

- RH Ø8×2.0 mm
- 360° = 2.0 mm axial
- 90° = 0.5 mm axial
- korrekte Rotation + Translation läuft frei
- falsche Phasenrotation erzeugt messbare Gewindeüberschneidung

## Schraube ↔ Klemmplatte

- Spindelschulter drückt auf die äußere Plattenseite
- Ø6-Journal läuft durch Ø6.5-Bohrung
- innerer Retainer liegt vollständig in der Senkung
- Retainer ragt nicht über die innere Kontaktfläche hinaus
- Spindel kann Platte drücken und beim Aufschrauben zurückziehen

## Knob

- Knob und Spindel sind getrennte Teile
- AF10-Spindelantrieb passt mit dokumentiertem FDM-Spiel in den Knob
- axiale Retainer-Mutter/Kappe ist separat
- Hauptdrehmoment wird formschlüssig über den Sechskant übertragen

## Außenmaße

Der Build schreibt die maximale Breite des geschlossenen Systems inklusive Knob in den Report. Ziel: deutliche Verbesserung gegenüber v45/v47 und möglichst <690 mm bei 600-mm-Eurobox.

## Tragarm-Sanity-Check

Automatisch dokumentieren:

- Querschnittsfläche
- Flächenträgheitsmoment Ix
- statische Biegespannung/Enddurchbiegung bei 16 kg / 4 Armen
- 3×-Dynamikfall
- Rechen-E-Modul PETG = 1500 MPa

Referenzquerschnitt v50: 32×30-mm Doppelsteg-I-Profil mit 4.5-mm Flanschen und zwei 3.2-mm Stegen, A≈422.4 mm², Ix≈52,243 mm⁴.

## Build-Gate

Der GitHub-Actions-Job beendet sich mit Fehler, wenn ein harter Check fehlschlägt. Ein ZIP mit fehlgeschlagener Validierung darf nicht als finales v50-Artefakt hochgeladen werden.

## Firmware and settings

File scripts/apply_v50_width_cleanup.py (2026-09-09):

from pathlib import Path
import re

p = Path('scripts/build_v50.py')
s = p.read_text(encoding='utf-8')
orig = s

parts_anchor = 'PARTS = {\n'
if parts_anchor not in s:
    raise SystemExit('Could not locate final PARTS anchor for width cleanup')

inboard = r'''# ---------------------------------------------------------------------------
# Absolute final transverse-envelope architecture
# ---------------------------------------------------------------------------
PLATE_SPINDLE_Y = BOX_RIM_INNER_Y
NUT_ANCHOR_OFFSET = 15.8
NUT_Y0 = PLATE_SPINDLE_Y - NUT_ANCHOR_OFFSET
NUT_THREAD_Y0 = NUT_Y0 - NUT_THREAD_LEN
NUT_TAIL_Y0 = NUT_THREAD_Y0 - LEAD_NUT_TAIL_L
CAGE_Y0 = PLATE_SPINDLE_Y - 37.535
CAGE_Y1 = PLATE_SPINDLE_Y - 13.600
WIDTH_RIM_CLEAR = 0.20

# Remove the obsolete outboard plate guide/nut cage and under-rim tail from the
# already validated handed bases. Keep the crosshead through the rim-inner
# clearance plane, then rebuild the screw cage inward from there.
_OUTBOARD_TRIM_Y = BOX_RIM_INNER_Y - WIDTH_RIM_CLEAR
_outboard_trim = box(-260.0, _OUTBOARD_TRIM_Y, -80.0, 520.0, 180.0, 160.0)
BASE_RIGHT = BASE_RIGHT.cut(_outboard_trim).removeSplitter()
BASE_LEFT = BASE_LEFT.cut(_outboard_trim).removeSplitter()

PRINT_GUIDE_Y0 = CAGE_Y1 - 0.40
PRINT_GUIDE_Y1 = _OUTBOARD_TRIM_Y
_inboard_parts = [
    box(-78.0, PRINT_GUIDE_Y0, PRINT_GUIDE_Z0, 7.6,
        PRINT_GUIDE_Y1-PRINT_GUIDE_Y0,
        PRINT_BASE_PLANE_Z-PRINT_GUIDE_Z0),
    box(70.4, PRINT_GUIDE_Y0, PRINT_GUIDE_Z0, 7.6,
        PRINT_GUIDE_Y1-PRINT_GUIDE_Y0,
        PRINT_BASE_PLANE_Z-PRINT_GUIDE_Z0),
    box(-78.0, CAGE_Y0-0.1, PRINT_BASE_PLANE_Z-PRINT_FRAME_TIE_T,
        156.0, CAGE_Y1-CAGE_Y0+0.2, PRINT_FRAME_TIE_T),
]
for sx in SPINDLE_X:
    _inboard_parts.append(box(sx-11.0, CAGE_Y0, PRINT_FRAME_BOSS_Z0, 22.0,
                              CAGE_Y1-CAGE_Y0,
                              PRINT_BASE_PLANE_Z-PRINT_FRAME_BOSS_Z0))
INBOARD_CAGE = fuse_all(_inboard_parts)
BASE_RIGHT = BASE_RIGHT.fuse(INBOARD_CAGE).removeSplitter()
BASE_LEFT = BASE_LEFT.fuse(INBOARD_CAGE).removeSplitter()

for sx in SPINDLE_X:
    _nut_pocket = box(sx-8.35, NUT_THREAD_Y0-0.35, 23.65,
                      16.7, NUT_THREAD_LEN+0.70, 21.0)
    _tail_pocket = box(sx-6.2, NUT_TAIL_Y0-0.25, SPINDLE_Z-10.25,
                       12.4, LEAD_NUT_TAIL_L+0.50, 6.0)
    _tunnel_y0 = CAGE_Y0 - 0.50
    _tunnel_y1 = PLATE_SPINDLE_Y - PLATE_Y + 0.50
    _spindle_tunnel = cyl_y(5.90, _tunnel_y1-_tunnel_y0,
                            sx, _tunnel_y0, SPINDLE_Z)
    _pin_y = NUT_Y0 - LEAD_NUT_PIN_Y
    _pin_z = SPINDLE_Z + LEAD_NUT_PIN_Z
    _pin_bore = cyl_x(LEAD_NUT_PIN_HOLE_D/2.0, 24.0, sx-12.0, _pin_y, _pin_z)
    _head_service = cyl_x(3.55, 3.0, sx-14.0, _pin_y, _pin_z)
    _clip_service = cyl_x(4.10, 4.0, sx+11.0, _pin_y, _pin_z)
    for cutter in (_nut_pocket, _tail_pocket, _spindle_tunnel,
                   _pin_bore, _head_service, _clip_service):
        BASE_RIGHT = BASE_RIGHT.cut(cutter)
        BASE_LEFT = BASE_LEFT.cut(cutter)

for xc in CLAMP_X:
    _pivot = cyl_x(PIN_HOLE_D/2.0, 40.0, xc-20.0, PIN_Y, PIN_Z)
    BASE_RIGHT = BASE_RIGHT.cut(_pivot)
    BASE_LEFT = BASE_LEFT.cut(_pivot)
BASE_RIGHT = BASE_RIGHT.removeSplitter()
BASE_LEFT = BASE_LEFT.removeSplitter()
BASE = BASE_RIGHT
if (not BASE_RIGHT.isValid() or len(BASE_RIGHT.Solids) != 1 or
        not BASE_LEFT.isValid() or len(BASE_LEFT.Solids) != 1):
    raise RuntimeError('Inboard width cleanup broke handed BASE topology')

# Closed plate body is entirely inboard of the rim. Only the lower hook reaches
# 4.2 mm outward under the inner rim edge. Positive opening travel moves -Y.
PLATE_BODY_Y0 = BOX_RIM_INNER_Y - PLATE_Y
PLATE_HOOK_Y0 = BOX_RIM_INNER_Y - WIDTH_RIM_CLEAR
PLATE_HOOK_Y1 = BOX_RIM_INNER_Y + UNDERHOOK
PLATE = box(-PLATE_X/2, PLATE_BODY_Y0, PLATE_Z0,
            PLATE_X, PLATE_Y, PLATE_Z1-PLATE_Z0)
PLATE = PLATE.fuse(box(-PLATE_X/2, PLATE_HOOK_Y0,
                       RIM_BOTTOM_Z-UNDERHOOK_T, PLATE_X,
                       PLATE_HOOK_Y1-PLATE_HOOK_Y0, UNDERHOOK_T))
for sx in SPINDLE_X:
    PLATE = PLATE.cut(cyl_y(PLATE_HOLE_D/2, PLATE_Y+1.0,
                            sx, PLATE_BODY_Y0-0.5, SPINDLE_Z))
    PLATE = PLATE.cut(cyl_y(6.0, 2.0, sx, PLATE_BODY_Y0, SPINDLE_Z))
PLATE = PLATE.removeSplitter()

# Proper Z180 rotations reverse local Y without reflecting the solids, so RH8x2
# chirality, spindle Z=31 and every frozen X datum remain unchanged.
for _shape in (LEAD_NUT, SPINDLE, KNOB, CAP_NUT):
    _shape.rotate(App.Vector(0,0,0), App.Vector(0,0,1), 180.0)
LEAD_NUT = LEAD_NUT.removeSplitter()
SPINDLE = SPINDLE.removeSplitter()
KNOB = KNOB.removeSplitter()
CAP_NUT = CAP_NUT.removeSplitter()

'''
s = s.replace(parts_anchor, inboard + parts_anchor, 1)
s = s.replace("    'eurobox_v50_rack_stay_support_universal': STAY_SUPPORT,\n", '')

old = '''V['plate_motion'] = []
for d in [0, 1, 2, 3, 4, 4.5, 5.0, 5.5]:
    pl = PLATE.copy(); pl.translate(App.Vector(0,d,0))
    V['plate_motion'].append({
        'open_mm': d,
        'base_common_mm3': round(BASE.common(pl).Volume, 6),
        'rim_common_mm3': round(RIM.common(pl).Volume, 6),
        'underhook_inner_y_mm': round(BOX_EDGE_Y-UNDERHOOK+d, 3),
    })'''
new = '''V['plate_motion'] = []
for d in [0, 1, 2, 3, 4, 4.5, 5.0, 5.5]:
    pl = PLATE.copy(); pl.translate(App.Vector(0,-d,0))
    V['plate_motion'].append({
        'open_mm': d,
        'base_common_mm3': round(BASE.common(pl).Volume, 6),
        'rim_common_mm3': round(RIM.common(pl).Volume, 6),
        'underhook_outer_y_mm': round(PLATE_HOOK_Y1-d, 3),
        'inner_rim_release_clearance_mm': round(
            BOX_RIM_INNER_Y-(PLATE_HOOK_Y1-d), 3),
    })'''
if old not in s:
    raise SystemExit('Could not replace final plate-motion validation')
s = s.replace(old, new, 1)
s = s.replace(
    'probe = cyl_y(PLATE_HOLE_D/2-0.05, PLATE_Y+1.0, sx, BOX_EDGE_Y-0.5, SPINDLE_Z)',
    'probe = cyl_y(PLATE_HOLE_D/2-0.05, PLATE_Y+1.0, sx, PLATE_BODY_Y0-0.5, SPINDLE_Z)', 1)
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

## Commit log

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2026-09-04 Switch CI build from v49 to clean-sheet v50
2026-09-04 Run base diagnostics after failed CAD step
2026-09-04 Fix v50 build geometry and validation before CAD run
2026-09-04 Apply v50 deterministic geometry fixups before CAD build
2026-09-04 Add automated v50 assembly preview
    [preview_v50.scad]
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2026-09-04 Generate v50 print spindle directly with CGAL
    [final_print_meshes.scad]
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2026-09-04 Exclude non-print BRep spindle reference from STL gate
2026-09-05 Render full mirrored v50 assembly with true box edges
    [preview_v50.scad]
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2026-09-05 Make v50 preview orientation explicit
    [preview_v50.scad]
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2026-09-05 Update validated v50 STL previews [skip ci]
    [ASSEMBLY_PREVIEW_v50.stl, eurobox_v50_base.stl, eurobox_v50_clamp_plate.stl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]
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2026-09-05 Validate v50 box clamp and publish only production STLs
2026-09-05 Fix FreeCAD clamp validation invocation and preview publishing
2026-09-05 Instrument v50 clamp validation failures
2026-09-05 Persist clamp crash checkpoint in validation artifact
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2026-09-05 Add spindle shoulder preload relief to v50 base
2026-09-05 Make clamp validation failure explicit in CI
2026-09-05 Fix spindle preload travel at outer cage
2026-09-05 Update validated v50 CAD outputs [skip ci]
    [ASSEMBLY_PREVIEW_v50.stl, eurobox_v50_assembly.FCStd, eurobox_v50_base.FCStd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]
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2026-09-05 Reinforce v50 rack clamp load path
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2026-09-06 Chain rack lock fixup into v50 build
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2026-09-06 Replace rack lock pin with printable eccentric cam
2026-09-06 Replace rack cam with screw clamp closure
2026-09-06 Separate rack screws nuts and threaded hand knobs
2026-09-06 Make rack screw closure continuous and validate M4 threads
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2026-09-06 Run explicit rack female-thread correction
2026-09-06 Fix rack female thread validation and deepen M4 grooves
2026-09-06 Trigger corrected rack female thread validation
2026-09-06 Fix v50 printable hardware interfaces
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2026-09-06 Match lead spindle mesh to longer retainer stud
    [final_print_meshes.scad]
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2026-09-06 Restore separate lead nuts and strengthen printable threads
2026-09-06 Run final separate-nut thread correction
2026-09-06 Restore spindle shoulder clearance in v50 base
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2026-09-06 Fix printable rack M4 female thread profile
2026-09-06 Run final printable M4 rack thread correction
2026-09-06 Fix final M4 thread patch for hex-drive knobs
2026-09-06 Generate canonical watertight rack M4 nut mesh
    [final_print_meshes.scad]
2026-09-06 Regenerate rack M4 nut with CGAL before mesh validation
2026-09-06 Make rack M4 nut thread continuous through full height
2026-09-06 Remove rack M4 nut chamfers for continuous thread
    [final_print_meshes.scad]
2026-09-06 Lengthen rack M4 nut to eight full thread turns
2026-09-06 Match final rack M4 nut mesh to eight-turn long nut
    [final_print_meshes.scad]
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2026-09-06 Expose rack M4 thread on bore wall
    [final_print_meshes.scad]
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2026-09-06 Use true radial-Z helix for printable M4 nut
    [final_print_meshes.scad]
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2026-09-07 Preserve rack M4 thread block in RH8x2 master pass
2026-09-07 Apply matched rack M4 thread pair after final M4 geometry pass
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2026-09-07 Rebuild rack M4 nut from scratch
    [rack_m4_nut.scad]
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2026-09-07 Fix rack M4 nut validation ordering
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2026-09-07 Rebuild rack M4 nut with open subtractive thread
    [rack_m4_nut.scad]
2026-09-07 Validate rebuilt rack M4 nut as subtractive female thread
2026-09-07 Trigger v50 rebuild with corrected rack M4 nut
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2026-09-07 Trigger v50 build with native OCC rack M4 nut
2026-09-07 Fix v50 lead screw retainer hardware
2026-09-07 Validate lead screw drive and retainer thread meshes
2026-09-07 Validate lead nut pin clip and retainer nut interfaces
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2026-09-07 Align fallback spindle mesh with canonical square drive
    [final_print_meshes.scad]
2026-09-07 Correct RH8x2 retainer nut phase
2026-09-07 Correct retainer nut phase validation
2026-09-07 Fix RH8x2 retainer nut phase to match spindle kinematics
2026-09-07 Align retainer nut validation phase with RH8x2 spindle motion
2026-09-07 Add real pin and clip service clearances in lead nut cage
2026-09-07 Center lead nut C-clip in its retaining groove
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2026-09-08 Apply mounting backstop after all v50 clamp fixups
2026-09-08 Fuse mounting backstop into final rack root geometry
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2026-09-08 Trigger v50 validation after preserving backstop pin bores
2026-09-08 Clear right rack pin head from mounting backstop
2026-09-08 Trigger v50 validation after pin-head service clearance
2026-09-08 Rebuild lead knob retainer with open RH8x2 thread
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2026-09-08 Strengthen 100 mm mounting backstop into beam roots
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2026-09-08 Preview handed rear bases [skip ci]
    [preview_v50.scad]
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2026-09-08 Fix v50 printability build ordering
2026-09-09 Trigger v50 validation after printability fix
    [rack_m4_nut.scad]
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2026-09-09 Keep v50 holder inside 600 mm box envelope
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2026-09-09 Fix inboard spindle thrust face
2026-09-09 Apply final inboard thrust-face correction
2026-09-09 Fix v50 mesh witness planes for print orientation
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2026-09-09 Place v50 rear stop in front of rack tube
2026-09-09 Restore pre-rewrite mesh orientation and gate every nut thread
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2026-09-09 Fix v50 backstop tube diameter datum
2026-09-09 Match rack pin to reinforced clevis
2026-09-11 Fix mesh validation for rotated printable parts
2026-09-11 Fix v50 mesh validator print orientation
2026-09-11 Fix handed STL mirror validation
    [apply_v50_width_cleanup.py]
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2026-09-11 Fix inboard width pass for current lead nut cartridge
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2026-09-11 Wire v55 RH8x2 phase correction into build
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2026-09-12 Harden RH8x2 retainer thread fit and actual spindle audit
2026-09-12 Wire final RH8x2 retainer fit hardening into build
2026-09-12 Fix retainer thread hardening source anchor
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2026-09-12 Overrun proven RH8x2 retainer cutter by one full pitch
2026-09-12 Derive retainer nut directly from proven threaded lead nut
2026-09-12 Keep retainer as axial slice of proven RH8x2 lead nut
2026-09-12 Use proven lead nut unchanged for RH8x2 retainer
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2026-09-12 Restore proper short RH8x2 knob retainer nut
2026-09-12 Rebuild knob retainer like the proven M4 nut
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2026-09-12 Overrun RH8x2 retainer cutter through both nut faces
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2026-09-12 Fix RH8x2 source kinematic state lookup
2026-09-12 Fix final clamp validator phase conventions
2026-09-12 Wire final width-validator phase correction
2026-09-12 Fix RH8x2 clamp phase validation after STEP round-trip
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2026-09-13 Add head-side walls and local screw-block floor support
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2026-09-13 Fix width validator patch after clamp runtime optimization
2026-09-14 Give generated CAD commits a checkable CI status
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2026-09-14 Widen rear backstop to 50 mm toward rear clamp
2026-09-14 Close screw support gaps and extend support-free head walls
2026-09-14 Update validated v50 CAD outputs
    [eurobox_v50_base.FCStd, eurobox_v50_base.step, eurobox_v50_base.stl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]
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2026-09-14 Close screw-cage front with spindle clearances
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2026-09-14 Run clamp-frame saddle bridge in final geometry pass
2026-09-14 Fuse clamp saddle bridge after final base geometry
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2026-09-15 Tie clamp wall into holms and cap frame-side ends
2026-09-15 Refit rack layout for 20mm front margin and INDX bed
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2026-09-15 Publish validated v60 CAD outputs
    [eurobox_v60_assembly.FCStd, eurobox_v60_base_left.FCStd, eurobox_v60_base_left.step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]
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2026-09-15 Add installed-orientation v60 preview scene
    [preview_v60.scad]
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2026-09-15 Publish corrected handed v60 meshes and preview
    [eurobox_v60_assembly.FCStd, eurobox_v60_base_left.FCStd, eurobox_v60_base_left.step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]
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2026-09-16 Apply proven v50 plate sweep clearance to final v60 core
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2026-09-16 Publish closed-root v60 meshes and preview
    [eurobox_v60_assembly.FCStd, eurobox_v60_base_left.FCStd, eurobox_v60_base_left.step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]
2026-09-16 Publish continuous-carrier v60 meshes and preview
    [eurobox_v60_assembly.FCStd, eurobox_v60_base_left.FCStd, eurobox_v60_base_left.step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]
2026-09-16 Fix v60 rack clamp screw closure geometry
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2026-09-16 Rework v60 box clamp front with wider spindle spacing and printable drops
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2026-09-16 Fix v60 publish for oversized assembly
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2026-09-17 Fix v60 box clamp thread pair and spindle sweep
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2026-09-17 Fix RH8x2 cartridge phase and kinematics
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2026-09-17 Fix left clamp hardware assembly transform
2026-09-17 Assemble replaceable front clamp cassettes
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2026-09-17 Expose clamp drives and reinforce RH8x2 cartridge
2026-09-17 Use rear-open reinforced clamp front v3
2026-09-17 Assemble corrected clamp front v3
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2026-09-17 Use thread-clear reinforced front v4
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2026-09-18 ci: run v60 validation on clamp/thread fix branch
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2026-09-18 fix: seat rack retainer nose on captive nut
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2026-09-18 Reinforce serviceable box clamp cage
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2026-09-18 Keep lead nut thread fix minimal
2026-09-18 Keep lead nut fix local and tolerate BRep contact noise
2026-09-18 Publish v60 rack hand knob
    [eurobox_v60_rack_hand_knob.FCStd, eurobox_v60_rack_hand_knob.step, eurobox_v60_rack_hand_knob.stl]
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2026-09-18 Fix knob clearance and captive manifold lead screw
2026-09-18 Use correct RH8x2 motion sign for final spindle
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2026-09-18 Orient front DROP for inverted base print
2026-09-18 Support actual inverted-print carrier flange with DROP
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2026-09-19 Complete inverted-print support around base frame
2026-09-19 Finish inverted-print support on front frame
2026-09-19 Fix v60 clamp knob clearance and lead-nut retention
2026-09-19 Tighten v60 lead-nut pin service clearances
2026-09-19 Center v60 box-clamp screw axis in fixed boss
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2026-09-19 Center v60 clamp stations in real carrier and increase holm clearance
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2026-09-19 Extend v60 top pin recess over full pin and reinforce cross top
2026-09-19 Reinforce v60 cross top behind top-load pin recess
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2026-09-19 Reinforce v60 front holm root and M4 nut floor
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2026-09-20 Fix lead screw pilot helix phase without axial shift
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2026-09-20 Preserve full round clearance in rack lower pin roof
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2026-09-20 Fix installed lead screw master translation scope
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2026-09-26 fix: redesign pin retainers as real snap clips [skip ci]
2026-09-26 feat: add v70 integrated lead screw [skip ci]
    [eurobox_v70_lead_screw_integrated.scad]
2026-09-26 feat: add v70 conical clamp retainer [skip ci]
    [eurobox_v70_conical_retainer_nut.scad]
2026-09-26 feat: add v70 pass-through clamp plate [skip ci]
    [eurobox_v70_clamp_plate.scad]
2026-09-26 fix: add pass-through hard stop to v70 lead screw [skip ci]
    [eurobox_v70_lead_screw_integrated.scad]
2026-09-26 fix: fit v70 conical retainer inside frozen base corridor [skip ci]
    [eurobox_v70_conical_retainer_nut.scad]
2026-09-26 fix: size v70 clamp bore for integrated screw assembly [skip ci]
    [eurobox_v70_clamp_plate.scad]
2026-09-26 docs: document v70 integrated lead screw concept [skip ci]
2026-09-26 build: add eurobox_v70_clamp_plate.stl [skip ci]
    [eurobox_v70_clamp_plate.stl]
2026-09-26 build: add eurobox_v70_conical_retainer_nut.stl [skip ci]
    [eurobox_v70_conical_retainer_nut.stl]
2026-09-26 build: add eurobox_v70_lead_screw_integrated.stl [skip ci]
    [eurobox_v70_lead_screw_integrated.stl]
2026-09-26 fix: extend v70 lead screw working thread [skip ci]
    [eurobox_v70_lead_screw_integrated.scad]
2026-09-26 docs: record v70 lead screw reach [skip ci]
2026-09-26 build: replace v70 STLs with valid binary meshes [skip ci]
    [eurobox_v70_clamp_plate.stl, eurobox_v70_conical_retainer_nut.stl, eurobox_v70_lead_screw_integrated.stl]
2026-09-26 feat: add v70 clamp v2 prototype source [skip ci]
    [eurobox_v70_clamp_v2.scad]
2026-09-26 build: add v70 clamp v2 prototype STL [skip ci]
    [eurobox_v70_clamp_v2.stl]
2026-09-26 docs: add v70 clamp v2 prototype dimensions [skip ci]
2026-09-27 feat: add v70 v3 eurobox_v70_clamp_v3 [skip ci]
    [eurobox_v70_clamp_v3.scad]
2026-09-27 feat: add v70 v3 eurobox_v70_bushing_v3 [skip ci]
    [eurobox_v70_bushing_v3.scad]
2026-09-27 feat: add v70 v3 eurobox_v70_lead_screw_v3 [skip ci]
    [eurobox_v70_lead_screw_v3.scad]
2026-09-27 feat: add v70 v3 eurobox_v70_knob_v3 [skip ci]
    [eurobox_v70_knob_v3.scad]
2026-09-27 docs: document v70 clamp v3 prototype [skip ci]
2026-09-27 build: add validated binary v70 v3 STLs [skip ci]
    [eurobox_v70_bushing_v3.stl, eurobox_v70_clamp_v3.stl, eurobox_v70_knob_v3.stl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]
2026-09-27 docs: record byte-exact v70 v3 STL validation [skip ci]
2026-09-27 feat: add v70 v4 eurobox_v70_clamp_v4 [skip ci]
    [eurobox_v70_clamp_v4.scad]
2026-09-27 feat: add v70 v4 eurobox_v70_bushing_half_v4 [skip ci]
    [eurobox_v70_bushing_half_v4.scad]
2026-09-27 feat: add v70 v4 eurobox_v70_lead_screw_v4 [skip ci]
    [eurobox_v70_lead_screw_v4.scad]
2026-09-27 feat: add v70 v4 eurobox_v70_knob_v4 [skip ci]
    [eurobox_v70_knob_v4.scad]
2026-09-27 build: add validated binary v70 v4 STLs [skip ci]
    [eurobox_v70_bushing_half_v4.stl, eurobox_v70_clamp_v4.stl, eurobox_v70_knob_v4.stl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]
2026-09-27 docs: document validated v70 v4 bearing redesign [skip ci]
2026-09-27 feat: add v70 v5 conical bearing refinement [skip ci]
    [eurobox_v70_bushing_half_v5.scad, eurobox_v70_bushing_half_v5.stl, eurobox_v70_clamp_v5.scad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]
2026-09-27 feat: add support-free v70 clamp v6 [skip ci]
    [eurobox_v70_clamp_v6.scad]
2026-09-27 docs: document v70 clamp v6 print strategy [skip ci]
2026-09-27 build: add validated binary v70 clamp v6 STL [skip ci]
    [eurobox_v70_clamp_v6.stl]
2026-09-27 feat: consolidate current carrier parts into v80 [skip ci]
    [eurobox_v80_base_left.FCStd, eurobox_v80_base_left.step, eurobox_v80_base_left.stl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]
2026-09-27 feat: add corrected v70 retaining pin and tight clips [skip ci]
    [eurobox_v70_lead_nut_pin_clip_v2.scad, eurobox_v70_lead_nut_pin_clip_v2.stl, eurobox_v70_lead_nut_retaining_pin_v2.scad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]
2026-09-27 feat: tighten v70 retaining clips v3 [skip ci]
    [eurobox_v70_lead_nut_pin_clip_v3.scad, eurobox_v70_lead_nut_pin_clip_v3.stl, eurobox_v70_rack_pin_clip_v3.scad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]
2026-09-27 fix: store exact binary v70 tight clips [skip ci]
    [eurobox_v70_lead_nut_pin_clip_v3.scad, eurobox_v70_lead_nut_pin_clip_v3.stl]
2026-09-27 feat: restore v50-style closed retaining clips in v70 [skip ci]
    [eurobox_v70_lead_nut_pin_clip_v4.scad, eurobox_v70_lead_nut_pin_clip_v4.stl, eurobox_v70_rack_pin_clip_v4.scad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]
2026-09-27 feat: promote approved v70 clips into v80 [skip ci]
    [eurobox_v80_lead_nut_pin_clip.scad, eurobox_v80_lead_nut_pin_clip.stl, eurobox_v80_rack_pin_clip.scad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]
2026-09-28 fix: promote corrected lead-nut retaining pin to v80 [skip ci]
    [eurobox_v80_lead_nut_retaining_pin.scad, eurobox_v80_lead_nut_retaining_pin.stl]
2026-09-29 feat: add v90 guided clamp builder [skip ci]
2026-09-29 fix: use current FreeCAD 1.1.3 AppImage asset
2026-09-29 Publish guided-clamp v90 binary CAD
    [eurobox_v90_base_left.FCStd, eurobox_v90_base_left.step, eurobox_v90_base_left.stl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]
2026-09-29 Publish complete guided-clamp v90 CAD set
    [eurobox_v90_base_left.FCStd, eurobox_v90_base_left.step, eurobox_v90_base_right.FCStd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]
2026-10-01 fix: rebuild and validate v90 retaining pin mesh [skip ci]
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2026-10-01 fix: repair retaining-pin STL winding [skip ci]
    [eurobox_v80_lead_nut_retaining_pin.stl, eurobox_v90_lead_nut_retaining_pin.stl]
2026-10-01 fix: publish repaired binary retaining pin in v90
2026-10-01 feat: add v100 local rack-frame relief builder [skip ci]
2026-10-01 Publish local rack-relief v100 CAD set
    [eurobox_v100_base_left.FCStd, eurobox_v100_base_left.step, eurobox_v100_base_left.stl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]
2026-10-01 fix: raise v100 frame relief to rack saddle [skip ci]
2026-10-01 fix: validate full-height v100 frame relief
2026-10-01 feat: add open screw slot to v100 rack lower [skip ci]
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2026-10-02 Publish v110 left-hand service retainer
    [eurobox_v110_base_left.FCStd, eurobox_v110_base_left.step, eurobox_v110_base_left.stl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]
2026-10-02 fix: use default retainer thread on both v100 bases [skip ci]
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2026-10-10 Add 60 mm spindle support sleeve for V70 emergency replacement
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2026-10-11 Replace 60 mm sleeve with 27.7 mm version
